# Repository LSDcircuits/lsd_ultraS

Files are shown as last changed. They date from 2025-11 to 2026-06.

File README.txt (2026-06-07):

lsd_ultraS

This project consist of using the BC557 & BC547 for pulsing and amplifying piezotransducers with the motive of measuring distance with the addition of using
optocoupler to demostrate circuit isolation.

containing:

- Documentation
- Schematics for PCB & for simulation
- Code for RP2040 C-SDK and PIO-ASM

documentation folder:

- Code description
- Measured results
- Circuit Description

schematics folder:

- Schematics for use with RP2040-Zero (lsd_ultraS)
- H-bridge output and amplifier (SIMULATIONS) 
- Spice models used for simulations

Code dir:

- PIO program for pulses
- C-SDK program executing the scheduling & logic
- C-SDK header files for Oled display -> from PICO_LSD (libs)
- Cmake.txt file

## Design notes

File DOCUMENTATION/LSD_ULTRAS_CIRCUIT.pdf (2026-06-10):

LSD_UltraS circuit documentation & derivation

This documentation derivations used to make the LSD_UltraS distance sensor.
The main device is a piezo transducer, the physics of the transducer shall be defined before trying to boost it since depending on how it drives current will decide how the circuit needs to be setup.

The piezo

A piezo transducer is physically a crystal with electrodes, its electrical behaviour can be described using the Butterworth-Van Dyke model. At 40KHZ the piezo acts as a open voltage source.

PIEZO definition

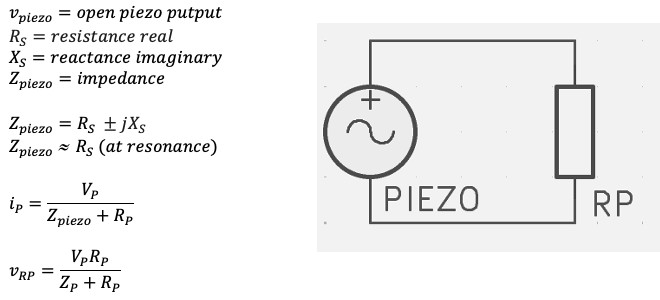
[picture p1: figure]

Transistor signal booster

To boost the signal to a readable digital value the component of choice would be a transistor, to set up the transistor the DC bias must be set for it to be in operating range. Once the DC bias is set the small signal AC model can be defined to solve for the required values of gain and saturation points.

DC analysis | AC analysis
Find operating point(Q point) | Finds gain, impedance, freq response
Uses full circuit | Small signal model with DC source as GND
Gives saturation points | Give how signal gets amplified
Yields: IC,VCE, VB,VE, VC | Yields: A, Rin, Rout

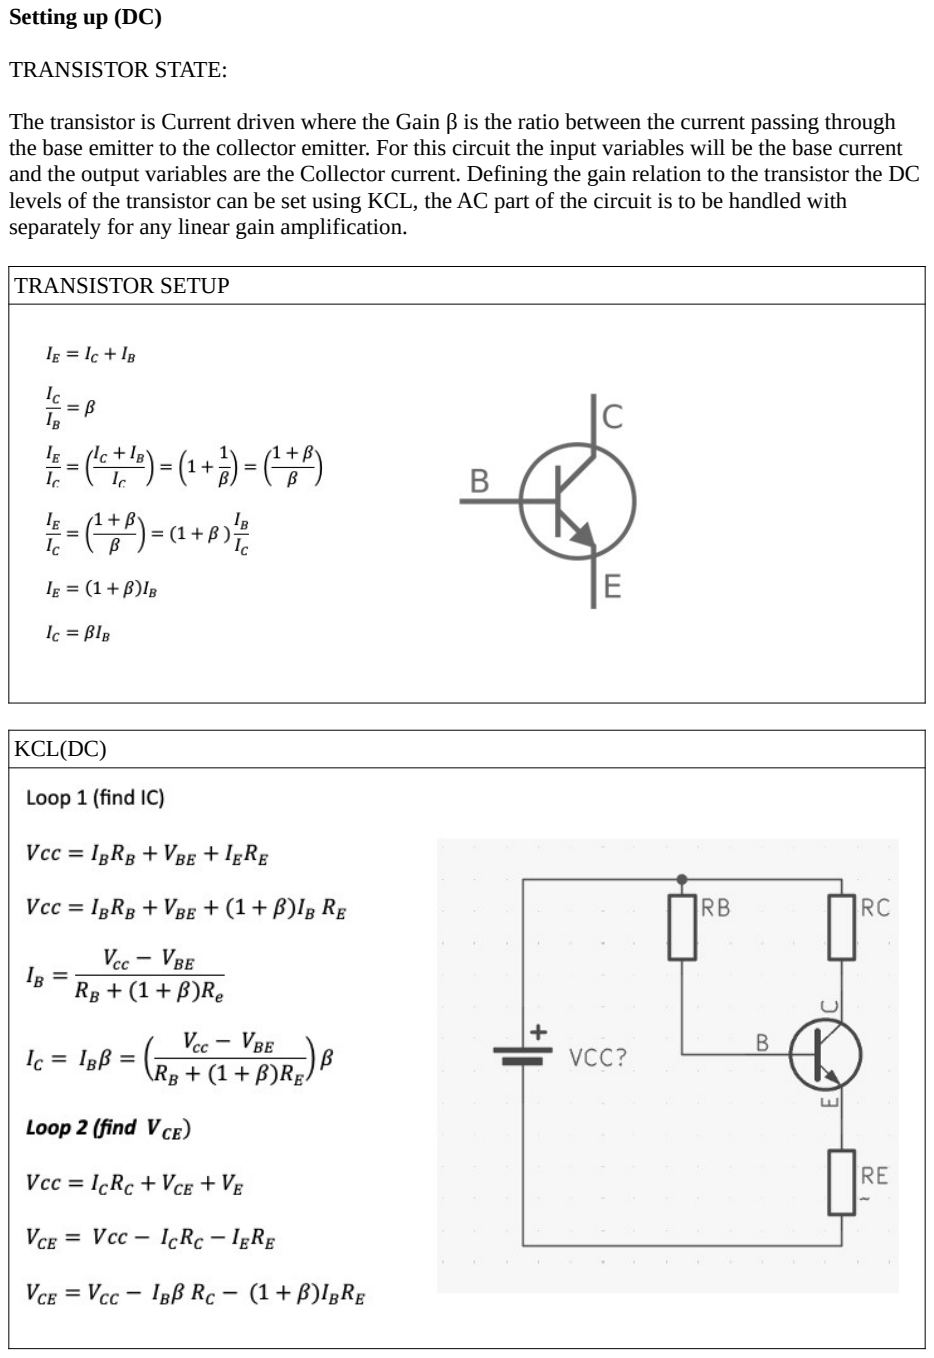
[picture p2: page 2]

Setting up (DC)

TRANSISTOR STATE:

The transistor is Current driven where the Gain β is the ratio between the current passing through the base emitter to the collector emitter. For this circuit the input variables will be the base current and the output variables are the Collector current. Defining the gain relation to the transistor the DC levels of the transistor can be set using KCL, the AC part of the circuit is to be handled with separately for any linear gain amplification.

TRANSISTOR SETUP

KCL(DC)

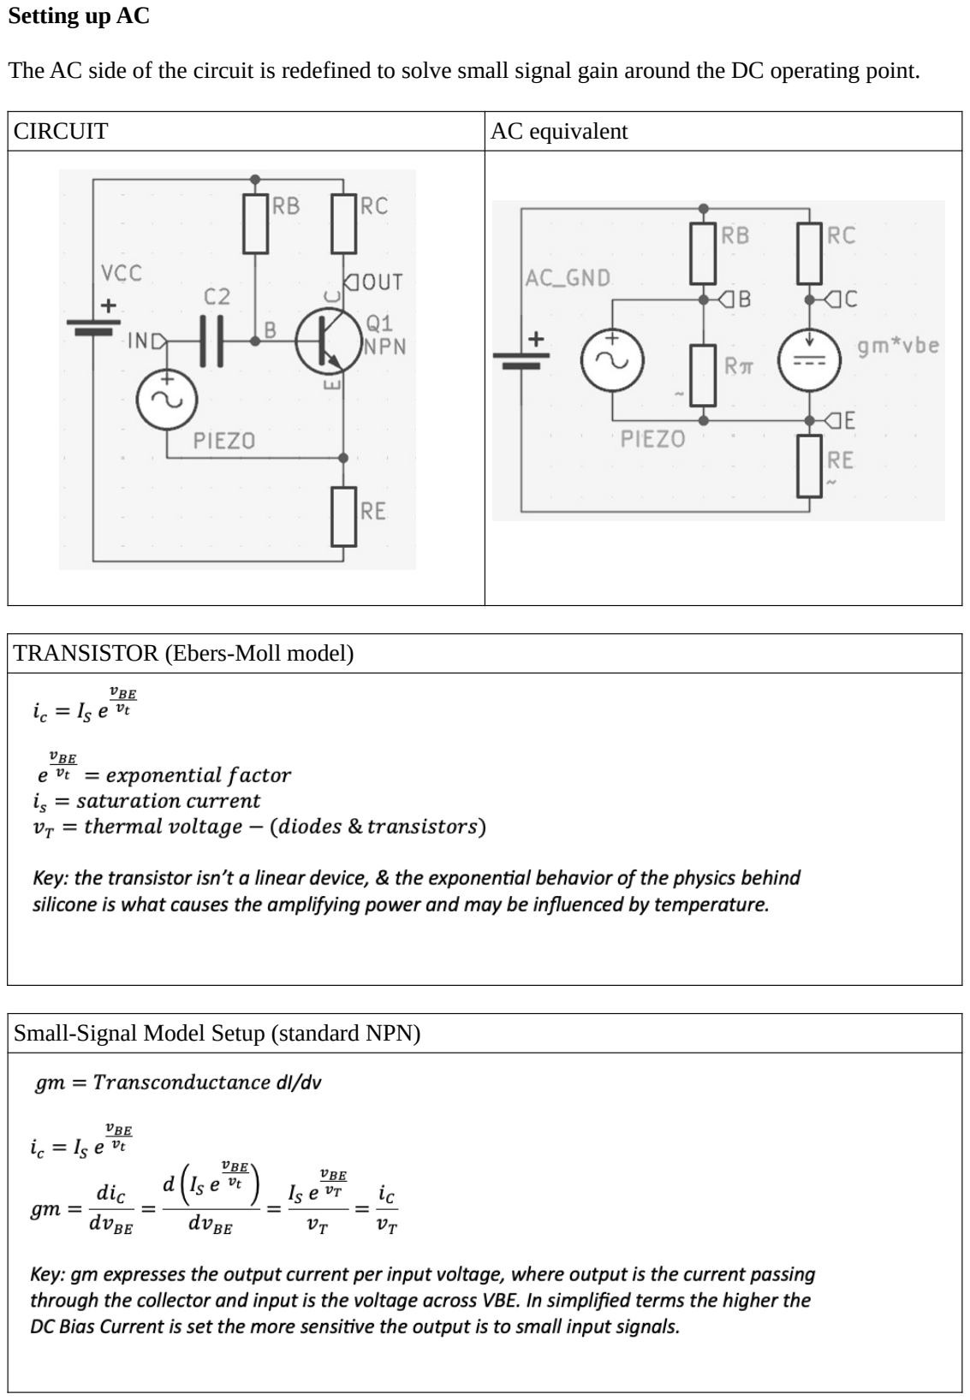
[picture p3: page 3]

Setting up AC

The AC side of the circuit is redefined to solve small signal gain around the DC operating point.

CIRCUIT | AC equivalent

TRANSISTOR (Ebers-Moll model)

Small-Signal Model Setup (standard NPN)

Interpreting the AC circuit

1. DC rails are treated a AC GND
2. Capacitor can be treated as a short (for solving gain)
3. Base emitter denoted as Rπ
4. Collector emitter denoted as current supply (gmvbe)

Using Ebers-Moll model the gain for small signal model can be used to find transconductance, this allows the equation to be solved algebraically since now the transistor is defined by 2 components which act as a current supply between CE and a resistor between BE, the resistor value shall be defined by the physical properties of the transistor between BE where the current supply can be defined by the (transconductance * vbe) since transconductance is the output current / vbe , cancelling out vbe and giving ic.

Base emitter Rπ

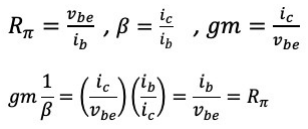
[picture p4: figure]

Solving for the transfer function

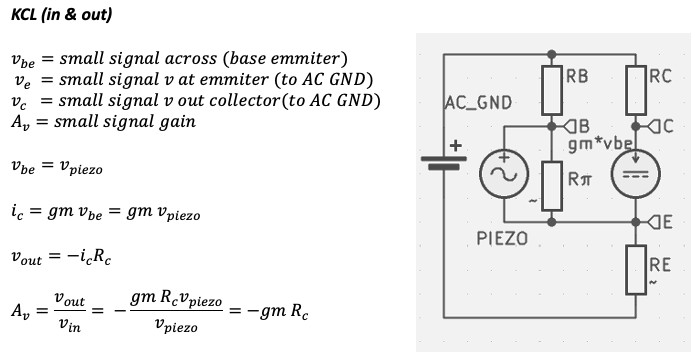
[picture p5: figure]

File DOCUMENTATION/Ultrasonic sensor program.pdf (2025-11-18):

## Ultrasonic sensor program

For this piezo transducer I’ve used the RP2040-zero dev board for its convenient size, layout ,power distribution and practicality of the RP2040 chip being able to do parallel tasks without an OS or RTOS.
Before going into the software its best to check the RP2040 block diagram.
This chip has many hardware peripherals which can be used with memory I/O mapping and some programmable blocks apart of the bus fabric.
To know which one to use for this projects the intentions must be defined:
1. Send pulses through 2 pins (1,0) (0,1) (PWM, PIO, GPIO)
2. Time measurement (program counter, ( delays + interrupt )
3. Pin monitoring, pulse received (GPIO, ADC)

For this project the PIO will be used for the pulses since it allows a single program to toggle 2 pins after the function is called once. For time measurement I will use a counter since its always running and I only need to dereference a pointer into a long and subtracts the values between memory calls.
For receiving the pulse I will use the GPIO for simplicity and will include ADC for range:

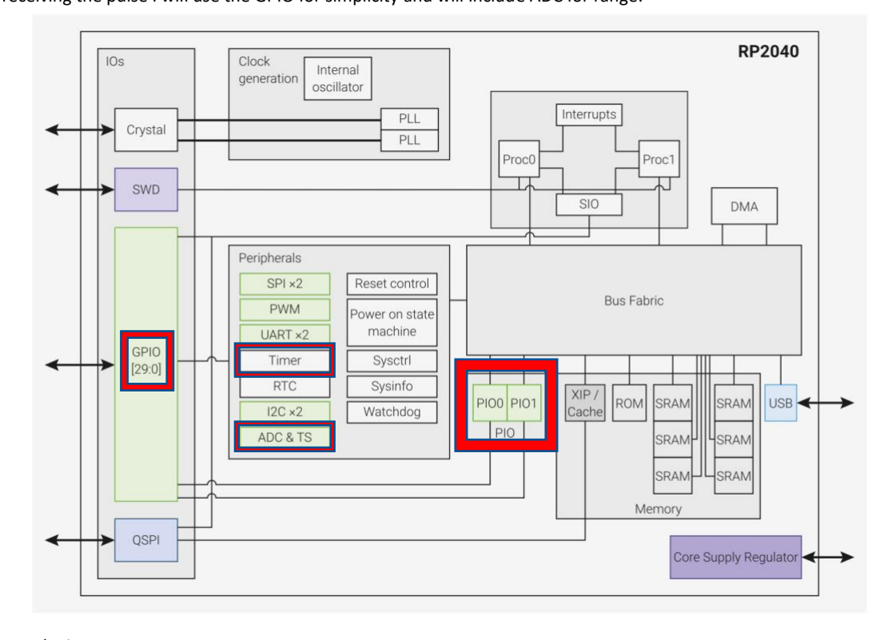
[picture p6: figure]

Program logic 1:
1. Send 8 pulses (using PIO) make a interrupt for after pulses finish
2. Use pulse interrupt to dereference counter T0
3. GPIO pin waits to be toggled
4. Once GPIO pin is toggles dereference counter T1
5. Use time difference to get distance of wave travelled.

Program logic 2:
1. Send 8 pulses (using PIO) make a interrupt for after pulses finish
2. Use pulse interrupt to dereference counter T0
3. ADC waits to read a threshold value
4. Once ADC above or below value, dereference counter T1
5. Use time difference to get distance of wave travelled.

## PIO program

The PIO is similar to a FPGA in practice. Its programmed in a very simple assembler with only 9 instruction set which is very limiting for anything out of hardware control or simple Boolean operations. For the case of toggling pins its perfect. Only 1 PIO state machine is needed using both input and output shift registers.
Take in account the PIO has a seemingly complex setup to configure before programming, the code has (PIO_C_SDK_init) explained in the notes which is consist of memory flow
management, here I will go over
the actual PIO program only.

PIO memory:

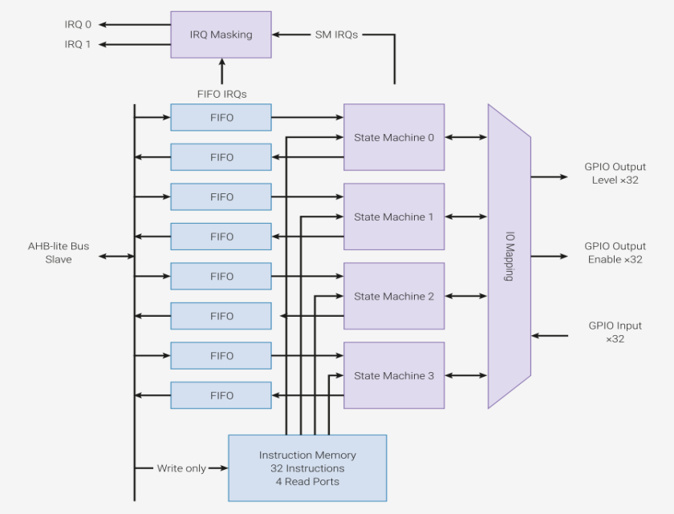
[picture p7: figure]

Memory | Description | Function
Offset | address instruction memory | Configures program (where its loaded and executed from)
TX & RX | input and output buffers TX and RX between PIO & CPU | Temporary 4 word Queue for receiving and sending (32Bit string)
ISR & OSR | input shift register & output shift register | Used for shifting data/ common in assemblers (pull, push, in, out)
Scratch X & Y | scratch registers | Temporary loop variables inside PIO program.
Direction | CPU function | PIO function | FIFO used | Shift register used
CPU -> PIO | Pio_sm_put_blocking() | Pull | TX fifo | OSR
PIO -> CPU | Pio_sm_get_blocking() | Push | RX fifo | ISR

For this memory procedure the PIO program can be written, the C-sdk sends the number of pulses to TX FIFO the PIO pulls the TX fifo into OSR and the Pio moves OSR to X using the mov command. This gives a variable which can be used, then the loop starts. The loop for pins has a nop instruction, so empty instruction of 1 clock to pull a pin high and low through changing 2 bit values (0b01, 0b10) in the loop there’s 2 instructions once completed the x register gets reduced by 1 and jumped back to loop start, (jmp x-- , loop) when x = 0 reducing it goes to -1 and for PIO this only works if X > 1 otherwise the program continues, this means that the loop cycles the n times which x is, so if X = 10 it will cycle 10 times, fist cycle x = 9 2nd it will be 8 and so on till zero then it continues to next instruction set.

.program pulse
.side_set 2 opt ; bits used to control pins (2 bits)

; The PIO waits to provide a pulse count
.wrap_target
pull block | ; block until CPU writes a word to TX FIFO, so pulls to OSR when block is full
mov x, osr | ; mov from OSR to scratch X to be used in program

loop:
nop | side 0b01 [1] ; first half of pulse from side set = 0b[2] = (pin1,pin2) = (01) [true]
nop | side 0b10 [1] ; second half of pulse from side set = 0b[2] = (pin1,pin2) = (01) [true]
jmp x--, loop | ; decrement X and loop if not zero so after each pulse it - the x register and jumps back
; after X = 0 decrement becomes -1 which instructs to move next, (strange but native to PIO)

; After finishing all pulses, notify CPU
mov isr, null | ; clear ISR (just to be safe)
set pindirs, 0 | ; optionally release the pins (if needed)
push block | ; push ISR (0) to RX FIFO as completion flag

.wrap
C – SDK

The SDK is divided by 2 parts the major part is setting up the PIO but wont be covered here but can be found on the PICO datasheet in chapter 3, and the code it self has it explained step by step. (The program has this order USING I/O):
GPIO:
(Setup Pio → Start PIO SM → interrupt → take counter values & wait for GPIO to go high → GPIO High counter value 2 → (dt * a ) ADC:
(Setup Pio → Start PIO SM → interrupt → take counter values & wait for GPIO to go high → GPIO High counter value 2 → (dt * a )

For this section the most important part is the use of the ADC and GPIO. There’s 2 options when reading a high Pin. The first Is using the GPIO peripherals which logic operates between (1.8-3.3 +- 0.5 V) these values are Boolean which is more intuitive for the programming side but requires more hardware for reliable readings. The second is the ADC, using the ADC is slightly more complex than using the GPIO since it needs to be configured to get triggered by a value within a range meaning more core power is needed with the benefit of over 1m range with amp and 30cm using no amplifier.

GPIO_program:

SDK high level functions:
gpio_init(); | gpio_set_dir(); | gpio_get();
Initiation | Sets pins | Gets status

PICO_LSD higher level functions:
pulse_setup(); | Read_timer_raw_macro2(); | oled_print_value();
Sets PIO Pulse | Reads timer value | Prints to SSD1036 LCD

Using the high level functions of the SDK is fast and reliable enough for a rising edge detection, the pulse setup function is within the main file and is just to setup the memory for PIO which executes a like mentioned in the (PIO_PROGRAM_SECTION), read timer macro is also within the file and takes ( [TL (*(volatile uint32_t*)(0x40054024))] & [(*(volatile uint32_t*)(0x40054028))] ) and buffers those register values into uint64_t which allows it to count to 580000 years.

For the rising edge, the detection loop is stuck at ( gpio == 0 ) comparing current time and measured time + threshold. This is so that only useful time measurements get calculated, another reason keeping it on a low loop gives the processor less work since detecting a rising edge using (Gpio == 1) causes the program to only execute when its high and not after its ben high, alternatively using a variable which saves the value till loop is completed is more intuitive but requires a extra variable and processing power (negligible but elegance!)
Given there’s a rising edge detected the program leaves the loop and takes the timer value for t1 and calculates distance using the speed of sound. These values are passed on to the printf(); and to oled_print_value(); afterward

void pulse_gpio(){
const uint8_t ECHO_PIN = 27;
const double SOUND_SPEED_CM_PER_US = 0.0344; gpio_init(ECHO_PIN);
gpio_set_dir(ECHO_PIN, GPIO_IN);
while (1) {
// Send the pulse
pulse_setup();
uint64_t t0 = read_timer_raw_macro2(); // Immediately after pulse sent // Wait for echo rising edge (GPIO goes HIGH)
uint64_t timeout = t0 + 50000; // 50 ms timeout
uint64_t t1 = 0;
while (gpio_get(ECHO_PIN) == 0) {
if (read_timer_raw_macro2() > timeout) { printf("Timeout waiting for echo (rising edge)\n"); goto done;
}
}
t1 = read_timer_raw_macro2(); // Time when echo is detected (rising edge) // Calculate time difference and distance
double dt_us = (double)(t1 - t0);
double distance_cm = (dt_us * SOUND_SPEED_CM_PER_US) / 2.0; printf("Echo delay = %.0f us → distance = %.2f cm\n", dt_us, distance_cm); done:
oled_print_value(distance_cm);
sleep_ms(10); // avoid flooding
}
}

ADC program:

void adc_read_dist() {
adc_init();
adc_gpio_init(26);
adc_select_input(0);
while (1) {
uint64_t t1 = 0;
uint8_t raw = 10;
const int max_samples = 200; pulse_setup();
uint64_t t0 = read_timer_raw_macro2(); for (int i = 0; i < max_samples; i++){ raw = read_stable_adc(2);
printf("raw value = %u\n", raw); if(raw < min_v){
t1 = read_timer_raw_macro2();
float dt = (t1 - t0 - 200);
float distance = (dt * 0.0344)/2; printf("distance = %.2f cm\n", distance); oled_print_value(distance);
break;
}
}
sleep_ms(10);
}
}
adc_init(); | adc_gpio_init(); | Adc_select_input();
Initiation | Sets pins for ADC | set ADC block

PICO_LSD higher level functions:
pulse_setup(); | Read_timer_raw_macro2(); | oled_print_value();
Sets PIO Pulse | Reads timer value | Prints to SSD1036 LCD

The higher level function of the SDK are mainly used to setup the ADC hardware for the RP2040, the PICO_LSD libs are used for timing, setting the pulses and printing on the LCD display.

The ADC program consist of the ADC_INPUT coming directly from the BC547 amplifier before the optocoupler, the reason is because the optocoupler threshold is much lower than the lowest readable signal from the ADC, this allows to have a much larger range for input signal detection giving a doubled increase in range.

The main difference between the GPIO input and ADC input is instead of waiting for a rising edge it waits for a value to be below a threshold, the reason its below and not above a threshold is due to ADC pulled high, the GP PIN is pulled high internally so sending a AC signal will offset the ADC above and below the current reading value. Main rule is if pulled down use a above value and if pulled up use a below value but generally can very depending on the setup. (small changes to be made to follow the same flow as GPIO)

Main Loop:
int main() {
stdio_init_all();

// gpio input for dip switch gpio_init(SET_ADC);
gpio_set_dir(SET_ADC, GPIO_IN); gpio_init(SET_PULSE);
gpio_set_dir(SET_PULSE, GPIO_IN); gpio_init(SET_PULSE_OUT);
gpio_set_dir(SET_PULSE_OUT, GPIO_IN);

oled_init();
while(1){
if(gpio_get(SET_ADC) == 0 && gpio_get(SET_PULSE) == 1) { pulse_gpio();
} else if(gpio_get(SET_ADC) == 1 && gpio_get(SET_PULSE) == 0){ adc_read_dist();
} else {
// print no setting selected when i hav
}

}
}

The main loop is just the execution of the previous functions, to show the functionality of both ADC & GPIO input there’s a set of input pins which are pulled low using 10K resistors and pulled high via a 1K and dip switches, this allows for a program selection which directs to a loop for pulse_gpio or adc_read_dist the PICO has a hardware reset so I skipped a setup loop for now and keep it to turning the switches then doing a hardware reset.
Extra info:
There’s a few functions which aren’t mentioned here such as PIO program initiations and how its memory is managed this information can be found in (3.2 Getting started with PIO) on the SDK documentation, ( Chapter 3. PIO ) on RP2040 datasheet and in the PICO-SDK examples for example showcases on how to use the PIO. Its extremely well documented and rather simple compared to alternatives like FPGA’s.
PICO_LSD higher level functions are libraries I’ve made specifically for the PICO, these are personal libraries I use for my projects which I haven’t documented properly such as the SD1306 which uses the ASCII format to print Char strings onto a LCD, the concept behind this is out of scope since its more heavy on computer science side than in control theory or electrical engineering.

Sources:
https://www.raspberrypi.com/documentation/microcontrollers/pico-series.html#pico-1-family

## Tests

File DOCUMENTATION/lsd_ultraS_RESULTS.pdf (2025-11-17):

(Schematics)

The H_bridge has 2 inputs which oscillate (1,0)(0,1) in (IN_1,IN_2) this allows 2 x source voltage as pulses. Works since PNP uses low to close and NPN as high so by suing potential dividers only need 2 input for reverse polarity from a given port.

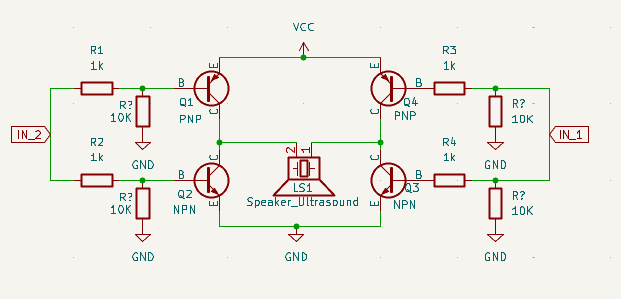
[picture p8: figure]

Output is at piezo, the amplifier stage has input PIEZO and output IN_ADC & IN_PULSE. The ADC input is for the amplified raw signal to ADC, the IN_PULSE is for GPIO setting. I used both in my test circuit.

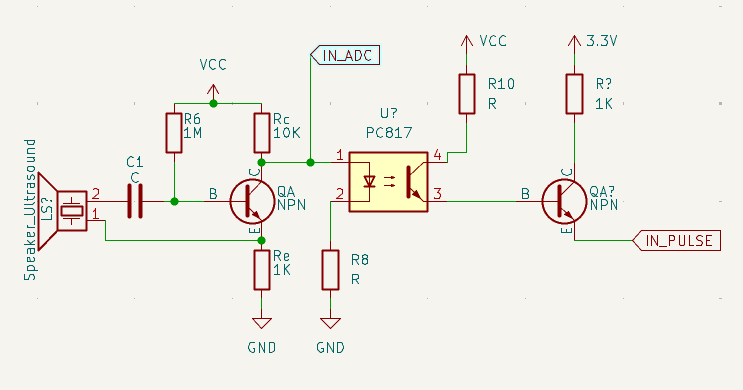
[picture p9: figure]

H_bridge output terminals to piezo transmitter:

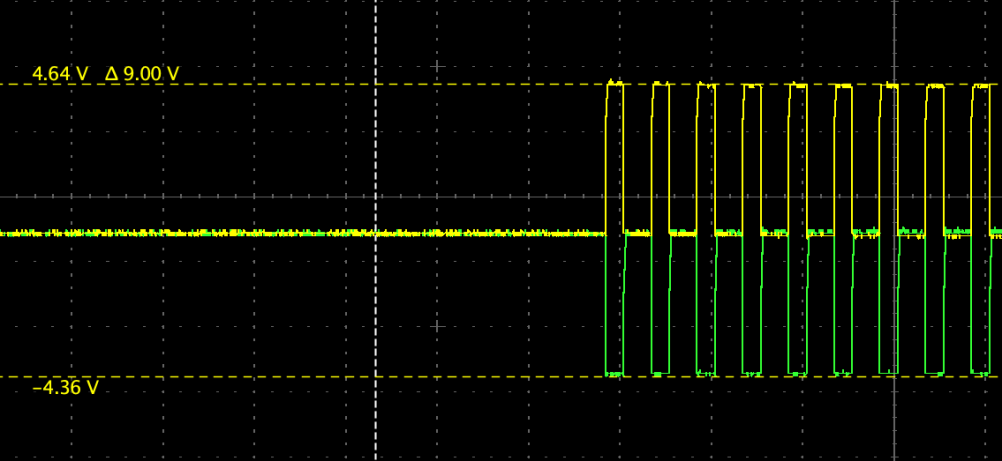
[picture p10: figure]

INPUT_PIEZO receiver: (60mv)

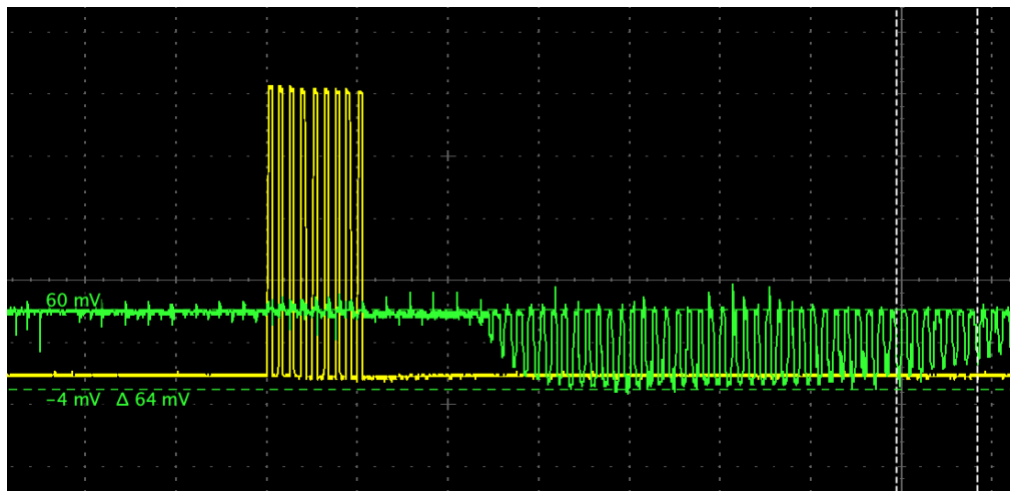
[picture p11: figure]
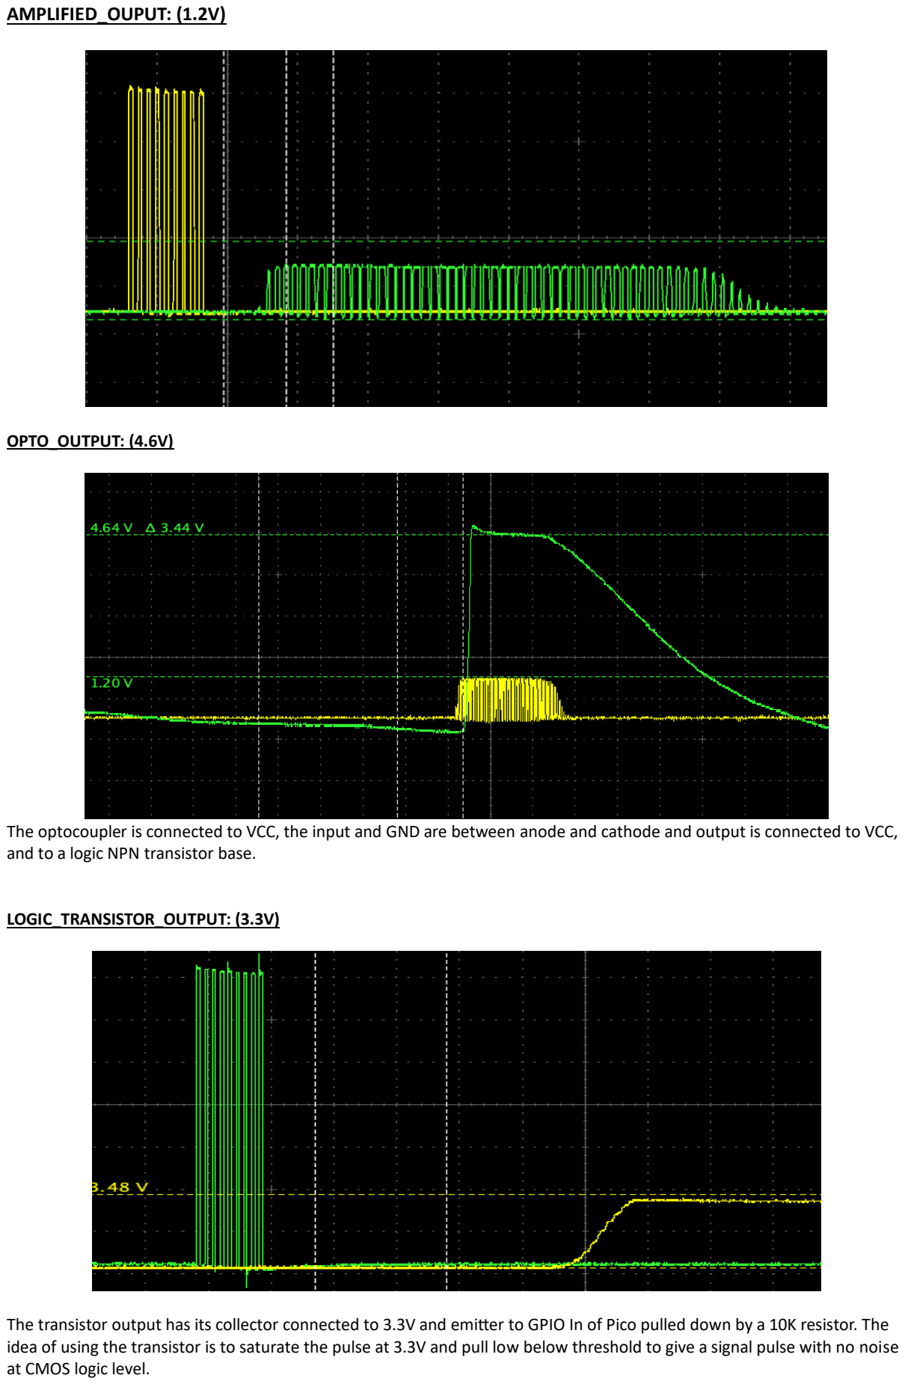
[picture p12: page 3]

AMPLIFIED_OUPUT: (1.2V)

OPTO_OUTPUT: (4.6V)

The optocoupler is connected to VCC, the input and GND are between anode and cathode and output is connected to VCC, and to a logic NPN transistor base.

LOGIC_TRANSISTOR_OUTPUT: (3.3V)

The transistor output has its collector connected to 3.3V and emitter to GPIO In of Pico pulled down by a 10K resistor. The idea of using the transistor is to saturate the pulse at 3.3V and pull low below threshold to give a signal pulse with no noise at CMOS logic level.

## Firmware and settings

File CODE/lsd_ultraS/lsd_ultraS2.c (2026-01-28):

#include <stdio.h>
#include "pico/stdlib.h"
#include "hardware/pio.h"
#include "hardware/adc.h"
#include "pulse.pio.h"
#include "SSD1306.h"


// program timer register
#define TL (*(volatile uint32_t*)(0x40054024))
#define TH (*(volatile uint32_t*)(0x40054028))

// for adc just a voltage value
#define min_v 5 
#define THRESHOLD 6

// gpio setting input
#define SET_ADC 0        // SETS ADC to the input for longer range
#define SET_PULSE 1      // SETS PULSE time difference
#define SET_PULSE_OUT 2  // this gives a output pulse to be read by ESP32 
// its 64 bit and needs to be biffered into a uint64 
// dereferenced register is assinged to low and high
// (64bit)  (32 bit high << 32 bit low) 
uint64_t read_timer_raw_macro2() {
    uint32_t hi1, lo, hi2;
    do {
        hi1 = timer_hw->timerawh;
        lo = timer_hw->timerawl;
        hi2 = timer_hw->timerawh;
    } while (hi1 != hi2);
    return ((uint64_t)hi1 << 32) | lo;
}

// Reads pin level (returns 1 for HIGH, 0 for LOW)
uint8_t gpio_in_mmio(uint8_t pin) {
    return (GPIO_IN >> pin) & 1u;
}

// pio initiation
void pulse_program_init(PIO pio, uint sm, uint offset, uint pin_base, float clkdiv) {
    pio_gpio_init(pio, pin_base); // gpio setup so this pin controlled by PIO 
    pio_gpio_init(pio, pin_base + 1); // gpio pin 2, pin 1 + 1 = 2

    // (PIO0, sm0, PIN1, number of pins, true= out, false = in) 
    pio_sm_set_consecutive_pindirs(pio, sm, pin_base, 2, true);

    // -> c is used as config memory
    pio_sm_config c = pulse_program_get_default_config(offset);

    // very important!, this assingns the pins to the pio wihtout this nothings happens
    // even when the program is running 
    sm_config_set_sideset_pins(&c, pin_base);

    // clock devider
    sm_config_set_clkdiv(&c, clkdiv);

    // here the config is loaded
    pio_sm_init(pio, sm, offset, &c);
}

void pulse_setup(){
    // PIO setup
    const uint PIN_BASE = 7;
    const float CLKDIV = 625.f;  
    PIO pio = pio0;
    uint sm = 0;
    
    // adress instruction memory where pulse_program is loaded
    uint offset = pio_add_program(pio, &pulse_program);

    // here the vaues are sent to the init from offset --> &c 
    pulse_program_init(pio, sm, offset, PIN_BASE, CLKDIV);

    // clear any fifos (OSR,ISR)
    pio_sm_clear_fifos(pio, sm);

    // restart the PIO0 & statemachine
    pio_sm_restart(pio, sm);

    // pio_sm_put_blockng sends a value to TX fifo (32 but queue)
    // this is just memory and stays there until its pulled by PIO
    pio_sm_put_blocking(pio, sm, 8);  

    // this starts the PIO SM
    pio_sm_set_enabled(pio, sm, true);
    // note this is a interrupt not a IQR interrupt
    // assgings a uint32 in a fucntion so functions wont end till its assgined
    // so fucntion ends when PIO program finishes. 8 40khz pulses in this case 
    uint32_t done = pio_sm_get_blocking(pio, sm);
}

void pulse_gpio() {
    const uint8_t ECHO_PIN = 27;
    const double SOUND_SPEED_CM_PER_US = 0.0344;

    gpio_init(ECHO_PIN);
    gpio_set_dir(ECHO_PIN, GPIO_IN);

    // Send the pulse
    pulse_setup();
    uint64_t t0 = read_timer_raw_macro2();  // Immediately after pulse sent

    // Wait for echo rising edge (GPIO goes HIGH) with timeout
    uint64_t timeout = t0 + 50000;  // 50 ms timeout
    uint64_t t1 = 0;

    while (gpio_get(ECHO_PIN) == 0) {
        if (read_timer_raw_macro2() > timeout) {
            printf("0\n");
            oled_print_value(0);
            return;
        }
    }

    t1 = read_timer_raw_macro2();  // Echo detected
    float dt_us = (double)(t1 - t0);
    float distance_cm = ((dt_us * SOUND_SPEED_CM_PER_US) / 2.0) - THRESHOLD;

    printf("1,%.0f\n", distance_cm);
    oled_print_value(distance_cm);
}



uint16_t read_stable_adc(int samples) {
    uint32_t sum = 0;
    for (int i = 0; i < samples; i++) {
        sum += adc_read();
    }
    return sum / samples;
}


float adc_read_dist() {
    const double SOUND_SPEED_CM_PER_US1 = 0.0344;
    adc_init();
    adc_gpio_init(26); 
    adc_select_input(0);

    uint64_t t1 = 0;
    uint8_t raw = 10;
    const int max_samples = 200;

    pulse_setup();
    uint64_t t0 = read_timer_raw_macro2();

    for (int i = 0; i < max_samples; i++) {
        raw = read_stable_adc(10);
        if (raw < min_v) {
            t1 = read_timer_raw_macro2();
            float dt = (t1 - t0 - 100);
            float distance = ((dt * SOUND_SPEED_CM_PER_US1)/2) - THRESHOLD;
            printf("%.0f\n", distance);
            oled_print_value(distance);
            return distance;
        }
    }

    return 0;
}


int main() {
    stdio_init_all();

    gpio_init(SET_ADC);
    gpio_set_dir(SET_ADC, GPIO_IN);
    gpio_init(SET_PULSE);
    gpio_set_dir(SET_PULSE, GPIO_IN);
    gpio_init(SET_PULSE_OUT);
    gpio_set_dir(SET_PULSE_OUT, GPIO_IN);

    oled_init();

    while (1) {
        bool adc_mode = gpio_get(SET_ADC);
        bool pulse_mode = gpio_get(SET_PULSE);

        if (adc_mode == 0 && pulse_mode == 1) {
            pulse_gpio();
            sleep_ms(1);
        } else if (adc_mode == 1 && pulse_mode == 0) {
            adc_read_dist();
            sleep_ms(5);
        } else {
            oled_clear();
        }
    }
}

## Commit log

2025-11-17 schematics
    intermediate upload, for schematics & few simulations as demo .
    the values can be adjusted for different controllers, whatever color u like - pink floyd ;0
    [Hbridge-pico.kicad_pcb, Hbridge-pico.kicad_sch, lsd_ultraS.kicad_pcb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]
2025-11-17 Update README.txt with project details and structure
    Expanded project description and added details about documentation, schematics, and code structure.
2026-01-28 Implement pulse and ADC distance measurement
    Add main functionality for pulse and ADC distance measurement.
    automatic change
2026-06-07 Update README to include optocoupler details
    Added information about using an optocoupler for circuit isolation.
